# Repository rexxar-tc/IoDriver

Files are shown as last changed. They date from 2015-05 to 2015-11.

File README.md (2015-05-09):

IoDriver
========
##About the IoDriver

The IoDriver is a custom, open-source RGBW LED driver for model lightsabers. Here you'll find source code, schematics, PCB files, firmware, binaries, documentation, and various other text files.

###Full Feature List

If you've come here from Tindie, you've seen a short list of what we thought were the most important features. Here's everything:

- Cross-platform software
- Up to 5 completely customizable profiles
- Up to 4 hours of runtime
- Full-spectrum RGBW color selection
- Integrated USB charging
- Expansion modules including bluetooth, sound, and accelerometer
- Choice of red, black, or silver buttons
- Easy installation-- no soldering necessary
- All profile data is stored on the driver

###Installation

It's fairly easy to install the IoDriver. First, you need to pull out any existing electronics in your saber. The easiest way I've found is to cut off the battery holder, then pry out the button and cut that out as well. The LED housing should just unscrew, allowing you to remove the existing LED.

Everything on the IoDriver has a connector, so you just need to fit the LED then the button, and plug it into the board. Easy. You may have to get a bit creative to fit all the wires into the LED housing, but it should work. It will take some force to put the new switch in, but with some gentle persuasion, it should go smoothly.

###What's All This Profile Jazz?

You get to define up to five profiles, with 20 color steps, and settable transition times between each. You can chose transistion effects as well. Currently there is the default gradient, solid colors, and a strobe effect. You can name each profile; you get 31 characters. All profile data, including names, are stored on board, so they will appear exactly as you set them no matter where you load up the software. You can also store as many profiles as you like locally on your computer.

When your profile is selected on your saber, it starts with the first color, then runs through a gradient to the next color. How fast this happens is based on the delay time you set. When it reaches the last color, you can choose to have it either cycle backwards through the profile, or just start over at the beginning.

###Why RGB_W_ LEDs?

RGB covers most of the color spectrum, but it's hard to get very light colors, and it's impossible to get true white. The separate red green and blue LEDs don't blend that well, so 'white' comes out as three colored spots or streaks. Having a white LED lets you get a true white, or pastel colors, if that suits you.

###Buttons

The switches specified in the BOM (and that are provided on Tindie) are meant to be pressed into sabers with a 7/16” opening. They're a shielded switch with red, black, or silver buttons. 7/16” seems to be a common size, so that's what I've selected these switches for. If your saber has a different size opening, you'll need to find your own switch. You need a momentary, normally-open (or normally-off) type.

###Software

The PC-side software is written in Perl, which works naively on Linux, and ports easily to Windows. It *should* be Mac compatible, though that's not been tested yet.

The software is fairly simple: You pick a profile number, 1-5, name it, pick your first color, transistion time and effect, then you pick a second color, and a third, etc. There is a preview button so you can see what your selected color looks like on your saber. You can also re-number your profiles, which changes the order in which they cycle through.

###Expansion Modules

Currently planned are a bluetooth module, accelerometer, and a sound expansion. None are available right now, but will be released in that order. Modules plug into the port on the top of the board, then stack on top of each other. The modules are screwed into mounting posts to keep them from coming loose.

Other modules are possible; feature requests can be posted on our GitHub [issue page] (https://github.com/rexxar-tc/IoDriver/issues).

###Other Details

The IoDriver comes with a 2400mAh lithium ion cell. There's circuitry on the board that will detect most chargers, and will charge at up to 2A, given a powerful enough charger. Most smartphone chargers are capable of supplying 1A or more. At a charge rate of 2A, the battery will charge from completely dead in just over an hour, and you get over 4 hours of use.

##That's It

That's about all you need to know about the IoDriver. If you're interested in building your own, or just want the nitty-gritty details, there's more documentation in the DOC folder. There's also schematics and Gerber files for getting your own PCBs made up.

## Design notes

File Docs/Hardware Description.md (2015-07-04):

##Overview

At the base level, the IoDriver is nothing more than a PWM LED driver with some fancy software. The hardware is relatively simple and straightforward. There are three major ICs on the board; the main ATmega328(p) microcontroller, a CYC7C65213 USB to serial converter, and a TI BQ24257 lithium-ion battery charger. In addition there is a Micrel MIC2876 5v boost converter, and a CAT25160 16kB EEPROM. The relatively high current to the LEDs is switched with FDN327N N-channel MOSFETs.

##General operation description

The LEDs are pulse width modulated to change their intensities and create different colors. The profiles store RGBW values, and we use a custom algorithm to generate the gradient sequence between each RGBW color (See color.cpp and component.cpp). The button is tied to an interrupt that increments the profile, as well as shut down and wake up the processor. Profiles are stored in EEPROM, and have a fairly simple structure.

####Charging

The Cypress USB to serial converter has the capability to detect when the device is plugged into a high-current USB port. When the IoDriver is plugged in, the TI charge controller starts up in standalone mode, with a charge current of 100mA, to prevent damaging an unknown charger. The TI device has an active-low power\_good output, which the main program checks at the start of each loop. When the power_good signal is detected, the IoDriver goes into charge mode. Within 100mS, the Cypress device will have determined the charger type (how much current it can supply) and toggles the states of two of its GPIO pins. The processor waits 200mS then reads the status of these GPIO lines, decides what the charge current should be, and sends that value to the TI device over the I2C bus. The TI charge controller is internally limited to 2A, which allows a charge from completely dead in just over an hour.

While the IoDriver is in charge mode, it polls the charge controller for the charge status (either done, charging, or error), then sets the LED to a low-intensity color to reflect that. Amber for charging, green for done, and blue or putple for error. A request or incoming data from USB will interrupt this loop to send or receive profile information, or a color preview override.

During charging, the LED will stay lit for about 5 minutes, then shut off. Once charging is complete, it will come back on green for another five minutes. The system is still powered on, so it will still immediately respond to any communication from the PC software.

Blue and purple are used for error indication to avoid confusion with the normal amber color. A purple error should only occur if the IoDriver is plugged in without a battery attached, and a blue error indicates any general charge error.

####Battery information

The ATmega device periodically checks the supply voltage, and when it falls below the BATTERY\_MINIMUM threshold (3.2V), it will blink red for about 10 seconds, then go into shutdown mode. The device can be woken back up, but a flag is raised in memory, locking it into low power mode until a charger is connected. In the event that the battery is deeply discharged, the TI charge controller can detect this, and will go through an algorithm to attempt to recover the cell.

The processor does not check supply voltage while charging, so as to not bail into shutdown mode when it's plugged in.

Additionally, there is battery protection circuitry on a dedicated board attached to the cell which protects against over- and under-charge, as well as over-current situations.

###Other design notes

The latest revision (G) saw the switch from the ATmega32u4 to the ATmega328(p) processor, as well as replacing the expensive Maxim USB charge detector IC with a USB to serial converter that has that functionality built in. This reduced both cost and complexity, and allowed us to go from a 4 layer PCB back to a much cheaper 2 layer board. Part of the motivation for this was the unpredictable stock of the ATmega32u4; we had to resort to sourcing the chips from ebay because all of the regular distributors were sold out. In addition, the ATmega328 processors cost about half of the 32u4.

Revision G also marks a major change in overall board design. All of the large parts have been put on the top side of the board, allowing for easier machine assembly.

Older hardware versions had an issue where the switching FETs weren't fully turning on. Changing all of the digital circuitry to run on a 5V rail provided by the boost converter solved this problem. Because of the high current requirements, the LED supply is still taken straight from the battery.

Off current is 2mA. This is low enough to be acceptable for a 2000mAh battery. It might be possible to reduce this further.

####Expansion connectors

There are two connectors on the front of the IoDriver board that are intended for expansion modules. Currently planned are a bluetooth module (with accompanying iOS/Android apps), an accelerometer module, and a sound board.

The large connector is just an SPI bus, with two chip select lines. It also carries all power to the expansion modules, as well as acting as the first-time ISP programmer for the ATmega328. Power to the expansion port is swiched with a MOSFET to prevent the modules consuming power when the system is supposed to be in sleep mode. Because of the body diode in the MOSFET, it's also possible to power the board from this connector for initial programming.

The second connector carries the I2C and RS232 Rx/Tx lines.

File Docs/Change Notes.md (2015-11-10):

##11/10/15
-*Hardware version incremented to H*
-*Added hardware support for accent LEDs* (user request)
-Added connector for buttons with built-in LEDs
-Added support for kill-key hard power switch. This simply disables the SMPS, which reduces power use to negligible levels
-We've officially used all available GPIO

##07/04/15
-*Firmware version incrementerd to 0.5.2*
-*Hardware version incremented to G2*
-Connected D+/D- pins on bq24257 for possible future use--currently unused in firmware
-Fixed major firmware issue where device would not wake from sleep mode, and had to be power cycled
-Fixed condition with bq24257 where it could not recover from completely dead battery--also can now be powered by USB with no battery connected
##06/07/15
-*Firmware version incremented to 0.5.1*
-*Hardware version incremented to G1*
-swapped pins 1 and 2
-moved CYC7C65213 Vcc pins from Vcc to Vbus. There was a latchup issue if the device was plugged into USB without a battery connected (no Vcc)
-added R10 on CYC7C65213; this is a current limiting resistor to prevent latchup
-RESET net wasn't properly connected
-deprecated recovery format functionality -- pin 24 (analog 1) is now free

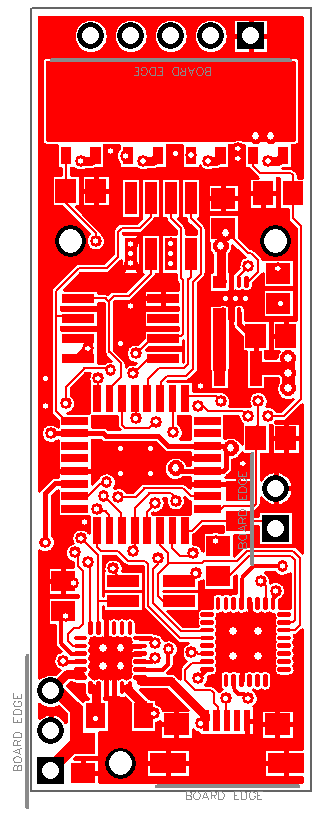
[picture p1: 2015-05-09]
Hardware/PCB-Top.bmp

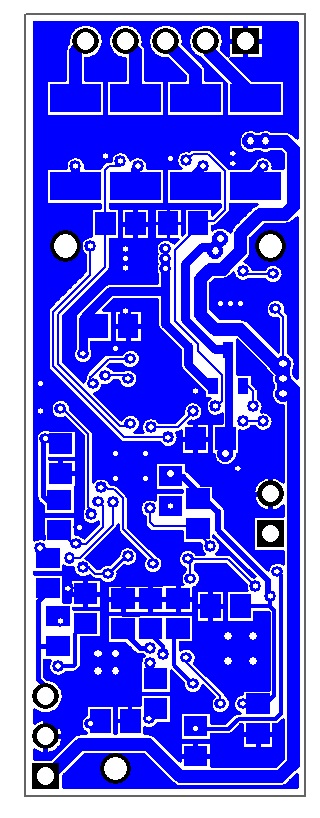
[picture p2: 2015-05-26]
Hardware/PCB-Bottom.jpg

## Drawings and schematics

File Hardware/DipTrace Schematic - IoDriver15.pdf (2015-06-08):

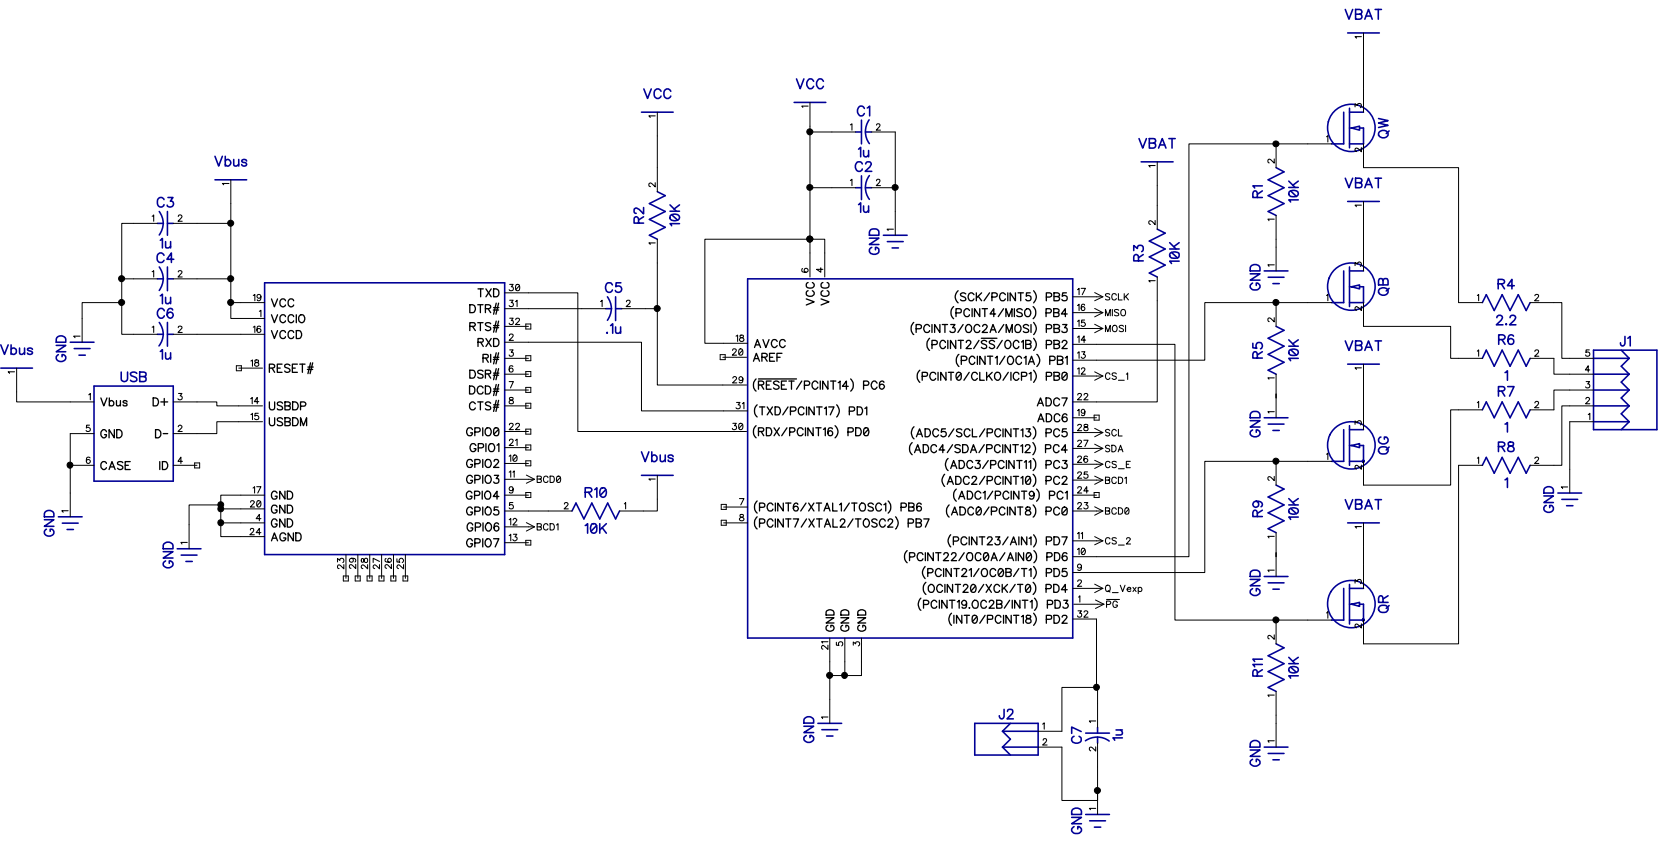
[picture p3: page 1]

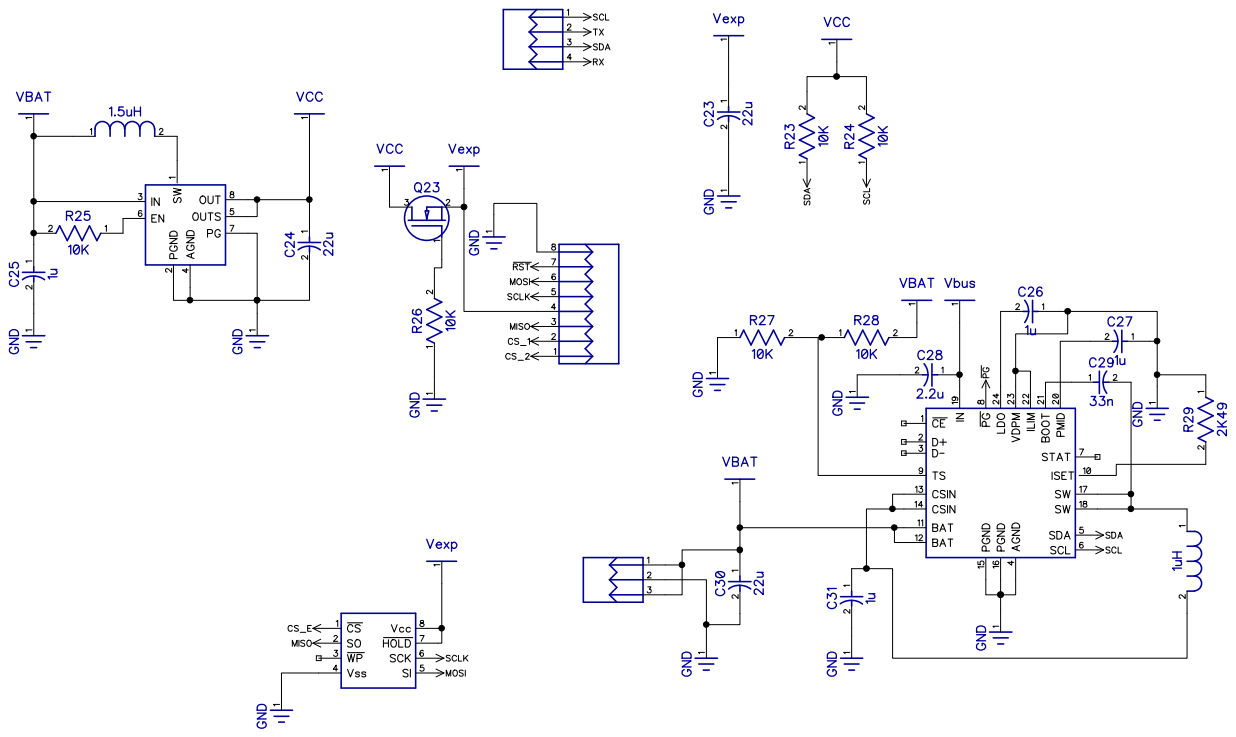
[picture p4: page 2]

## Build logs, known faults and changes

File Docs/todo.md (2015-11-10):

##ToDo
Include prebuilt firmware binaries
General code cleanup
Optimization of SPI EEPROM routines
Implement accent and button LEDs in firmware
Change pin numbers to match reassigned functions
Finish design for sound expansion
Wait for C to fix the GUI disconnect issue
Wait for C to implement accent LEDs in GUI
Wait for C to implement sound

##Bugs:
-GUI program will fail and disconnect when polling for connection status [Workaround: set polling period to 10 minutes]
-Sometimes color will freeze when plugging device in, pressing the button will switch it back to the charging color. (can't seem to reproduce?)
-Preview profile can sometimes get corrupted during transmission.
-Writing a single byte to the second EEPROM under specific conditions will fail with no warning.

##Fixed bugs:
-LED can sometimes stress SMPS to the point of overload, thermal shutdown.
Fix: changed LED supply back to battery voltage.
-Battery voltage drops due to LED current, causes premature shutdown [Workaround: battery voltage checking is disabled for now, relying on protection board]
Fix: Workaround caused Li protection circuit to isolate battery; charging circuit couldn't recover. Now averaging voltage over 10 seconds to account for voltage droop.
-Profile preview function in GUI doesn't work
Fix: program now actually checks if there's a preview profile coming in
-When resuming from sleep, it will switch to the next profile
Fix: program now checks if we're resuming from sleep; disables profile advance
-Device doesn't wake when plugged in while asleep
Fix: Moved PowerGood signal to interrupt pin
-Charge controller couldn't recover from fully discharged and isolated battery
Fix: Controller for some reason *requires* USB input to start up with no battery input: routed those connections

##Issues:
-Opening serial port causes a reset. This is by design, but GUI can't cope [Workaround: removed C4; this means firmware is not user updateable] May include manual reset button later to allow user updates.

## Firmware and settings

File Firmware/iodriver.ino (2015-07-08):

#include <cstdlib>

#include <Arduino.h>
#include <avr/sleep.h>
#include <avr/power.h>
//#include <EEPROM.h> // Don't remove this (commented) include. Needed for pre-build step parsing.
#include <Wire.h>
#include <SPI.h>
#include <SPI_io.hpp>
#include <iodriver.hpp>
#include <profile.hpp>
#include <profilehandler.hpp>
#include <EEPROMHandler.hpp>
#include <I2C.hpp>

bool plugged = false;
bool check_button = false;
bool bat_low = false;
unsigned long button_time = 0;
unsigned long average_time = 0;
int average_array[10] = {700,700,700,700,700,700,700,700,700,700};
int average_count = 0;
bool chg_preview = false;
bool sleep_tst = false;
bool is_asleep = false;

IoDriver::ProfileHandler ph;

int freeRam () {
  extern int __heap_start, *__brkval;
  int v;
  return (int) &v - (__brkval == 0 ? (int) &__heap_start : (int) __brkval);
}

void updateLED() {

    IoDriver::rgbw color;
    IoDriver::Profile* ap = ph.active();
    if ( ap ) {
        color = ap->get_color_value();
    } else {
        color = IoDriver::rgbw( 0, 0, 0, 0 );
    }
    analogWrite( PIN_LED_R, color.r );
    analogWrite( PIN_LED_G, color.g );
    analogWrite( PIN_LED_B, color.b );
    analogWrite( PIN_LED_W, color.w );
}

void setup() {
    //Serial.begin( 4800 ); //enable here for debug, otherwise when plugged in

    set_sleep_mode( SLEEP_MODE_PWR_DOWN );

    // Find all profiles' start addresses and store them,
    // then activate the first profile.
    (void)ph.enum_profiles();
    (void)ph.first_profile();

    //set pin modes
    pinMode( A1, INPUT );
    pinMode( PIN_BUTTON, INPUT_PULLUP );
    pinMode( PIN_POWERGOOD, INPUT_PULLUP );
    pinMode( PIN_BCD0, INPUT_PULLUP );
    pinMode( PIN_BCD1, INPUT_PULLUP );
    pinMode( PIN_LED_R, OUTPUT );
    pinMode( PIN_LED_G, OUTPUT );
    pinMode( PIN_LED_B, OUTPUT );
    pinMode( PIN_LED_W, OUTPUT );
    pinMode( PIN_CS_E, OUTPUT );
    pinMode( PIN_Vexp, OUTPUT );

    digitalWrite( PIN_Vexp, HIGH );     //turn on power to expansion bus

    attachInterrupt( 0, buttonPressed, FALLING );   //go to buttonPressed() when button on pin 2 goes from high to low
    attachInterrupt( 1, wakePlugged, FALLING );     //gp to wakePlugged() when device plugged into usb

    Wire.begin();
    SPI.begin();
}

void loop()
{
    checkPG();
    if ( !plugged )
    {
        //check battery voltage
        if (checkVoltage() < BATTERY_MINIMUM || bat_low == true )
        {
            bat_low = true;
            for( int b = 0; b < 5; ++b)
                blinkRed();

            disableCharge();
            digitalWrite( PIN_Vexp, LOW );   //turn off power to expansion bus
            sleep_enable();
            sleep_mode();
            digitalWrite( PIN_Vexp, HIGH );  //turn on power to expansion bus
        }

        else
        {
            if ( check_button ) {
                // If button is up, stop checking, increment profile, and re-enable button interrupts
                if ( digitalRead( PIN_BUTTON ) != 0 ) {
                    check_button = false;
                    ph.next_profile();

                // If button is still down, check whether it has
                // been down for 2 seconds
                } else {
                    unsigned long time_now = millis();
                    if ( time_now - button_time >= TIME_TO_SLEEP ) {
                        // Turn off the LEDs
                        digitalWrite( PIN_LED_R, LOW );
                        digitalWrite( PIN_LED_G, LOW );
                        digitalWrite( PIN_LED_B, LOW );
                        digitalWrite( PIN_LED_W, LOW );
                        check_button = false;
                        is_asleep = true;
                        digitalWrite( PIN_Vexp, LOW );      //turn off power to expansion bus
                        PRR |= 0b10000111;                  //turn off ADC, I2C, and UART
                        sleep_enable();
                        sleep_mode();
                        PRR &= 0b01111000;                  //turn on ADC, I2C, and UART
                        digitalWrite( PIN_Vexp, HIGH );     //turn on power to expansion bus
                    }
                }
            }
        updateLED();
        }
    }
    else if ( plugged && !chg_preview )
    {
        checkSerial();
        chargeState();
    }
    else if ( plugged && chg_preview == true )
    {
        checkSerial();
        updateLED();
    }
}

void buttonPressed()
{
    sleep_disable();
    //if we've just resumed from sleep, set check_button false so we don't change profile
    if ( is_asleep )
    {
        is_asleep = false;
        check_button = false;
        return;
    }
    if ( check_button )
        return;

    check_button = true;
    button_time  = millis();
}

void wakePlugged()
{
    sleep_disable();    //wake up system from sleep on charger connect
}

void checkPG()
{
    if ( digitalRead (PIN_POWERGOOD) == LOW && !plugged )       //if charge IC reports plugged in, and we weren't previously
    {
        plugged = true;
        Serial.begin(BAUDRATE);
        setupCharge();
        detachInterrupt(0);                                     //detach button interrupt
        attachInterrupt(0, buttonPressedCharge, FALLING );      //attach new interrupt to check battery state while charging
        bat_low = false;                                        //reset bat_low
        is_asleep = false;
    }

    else if ( digitalRead (PIN_POWERGOOD) == LOW && plugged)    //if charge IC reports plugged in, and we were previously
    {
        //do nothing
    }

    else if ( digitalRead (PIN_POWERGOOD) == HIGH && plugged)   //if charge IC reports unplugged
    {
        plugged = false;
        Serial.end();
        disableCharge();
        detachInterrupt(0);
        attachInterrupt( 0, buttonPressed, FALLING );           //and re-enable the interrupt
        chg_preview = false;                                    //cancel profile preview
        ph.first_profile();                                     //switch to first profile
    }

    else
    {
        plugged = false;        //just in case.
    }
}

void blinkRed()
{
    analogWrite(PIN_LED_R, 0);
    analogWrite(PIN_LED_G, 0);
    analogWrite(PIN_LED_B, 0);
    analogWrite(PIN_LED_W, 0);  //turn off all LEDs
    analogWrite(PIN_LED_R, 50); //turn on red LED
    delay(1000);                //wait one second
    analogWrite(PIN_LED_R, 0);  //turn it back off
    delay(2000);                //wait two seconds
    analogWrite(PIN_LED_R, 0);
    analogWrite(PIN_LED_G, 0);
    analogWrite(PIN_LED_B, 0);
    analogWrite(PIN_LED_W, 0);  //turn off all LEDs
    analogWrite(PIN_LED_R, 50); //turn on red LED
    delay(1000);                //wait one second
    analogWrite(PIN_LED_R, 0);  //turn it back off
    delay(2000);                //wait two seconds
}

int checkVoltage()
{
    long average_hold = 0;
    if( millis() - average_time >= 1000 )
    {
        average_array[average_count] = analogRead( PIN_BATTERY );
        average_time = millis();
        for( int a = 0; a < 10; ++a)
        {
            average_hold += average_array[a];
        }
        average_hold /= 10;

        if( average_count == 9 )
            average_count = 0;
        else
            average_count ++;

        return average_hold;
    }
    else
    {
        for( int a = 0; a < 10; ++a)
        {
            average_hold += average_array[a];
        }
        average_hold /= 10;
        return average_hold;
    }
}

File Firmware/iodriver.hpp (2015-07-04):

#ifndef _IODRIVER_HPP
#define _IODRIVER_HPP

#define FIRMWARE_VERSION_NUMBER	        "0.5.2"

#ifndef HARDWARE_VERSION_NUMBER
#define HARDWARE_VERSION_NUMBER         "G"
#endif

#define BAUDRATE                        57600 //serial port speed
#define SERIAL_DELAY                    1    //ms
//Pin definitions

#define PIN_BUTTON                  	2
#define PIN_POWERGOOD               	3
#define PIN_LED_W                   	6
#define PIN_LED_B                   	9
#define PIN_LED_G                   	5
#define PIN_LED_R                   	10
#define PIN_BCD0                        A0
#define PIN_BCD1                        A2
#define PIN_BATTERY                     A7

//power settings

#define TIME_TO_SLEEP                   2000 // milliseconds

                                             // ADC units
#define BATTERY_FULL                    839  // 4.1V
#define BATTERY_MINIMUM             	655  // 3.2V
#define BATTERY_CRITICAL            	614  // 3V
#define ADC_CONVERSION                  4.883  //converts ADC units to mV

#define TIME_INTERVAL_CONVERSION_FACTOR	10	// Multiply time interval by this to get milliseconds

//declarations

void buttonPressed();
void checkSerial();
void checkPG();
void setup_EE2();
void blinkRed();
int checkVoltage();
void checkVoltDebug();
void buttonPressedCharge();
void wakePlugged();

extern bool chg_preview;

/**
 * Data storage parameters
 **/
// Data formatting specs
#define CAL_OFFSET                       1025
#define BAT_LOW
#define EEPROM1_FIRST_PROFILE_OFFSET        0
#define PROFILE_INDEX_OFFSET                0
#define PROFILE_INDEX_SIZE                  1
#define PROFILE_NAME_OFFSET                 1
#define PROFILE_FIRST_DATA_OFFSET          32
#define PROFILE_COLOR_UNIT_SIZE             8
#define PROFILE_DATA_UNIT_SIZE              8
//#define PROFILE_COLOR_RGBW_OFFSET           0
//#define PROFILE_COLOR_TIME_INTERVAL_OFFSET  4
//#define PROFILE_COLOR_TIME_INTERVAL_SIZE    2
//#define PROFILE_COLOR_END_FLAG_OFFSET       6
#define PROFILE_DATA_TYPE_OFFSET            0
#define PROFILE_COLOR_RGBW_OFFSET           1
#define PROFILE_COLOR_TIME_INTERVAL_OFFSET  5
#define PROFILE_COLOR_TIME_INTERVAL_SIZE    2
#define PROFILE_COLOR_EFFECT_FLAGS_OFFSET   7
#define PROFILE_DATA_TYPE_COLOR             1
// Data limitations
#define EEPROM1_MAX_PROFILES                5
#define PROFILE_MAX_SIZE                    200
#define PROFILE_NAME_MAX_CHARS              31
#define PROFILE_MAX_DATACOUNT               21
// Specifications
#define EEPROM1_SIZE                        1024 // Used in EEPROMHandler
#define EEPROM2_SIZE                        16384
#define EEPROM_TOTAL                        EEPROM1_SIZE + EEPROM2_SIZE

#define EEPROM_H_VIRTUAL_SIZE               PROFILE_MAX_SIZE // Used in EEPROMHandler
#define HAS_SECONDARY_EEPROM

#endif // _IODRIVER_HPP

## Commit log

2014-04-20 Added schematic and PCB files
    Both in DipTrace format.
2014-05-23 Introduced Rev D changes
    [IoDriverRevC.gbl, IoDriverRevC.gbo, IoDriverRevC.gbs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]
2014-07-29 Vast and sweeping changes
    Decided to not use GitHub for a few months, then changed our mind, oops.
    [IoDriverRevC.gbl, IoDriverRevC.gbo, IoDriverRevC.gbs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]
2015-01-08 Rev G overhaul
    Completely redesigned hardware. Check HardwareDescription.md/design
    notes
    [IoDriver15.gbl, IoDriver15.gbo, IoDriver15.gbs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]
2015-01-08 Cleanup
    Accidentally left some Rev F files in place-- deleted those
    [IoDriverRevF.gbl, IoDriverRevF.gbo, IoDriverRevF.gbs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]
2015-04-15 Added SMPS to driver board
    Greatly increases brightness! Various improvements to software, remove
    shift register from board, added connector for bluetooth module.
    [IoDriver15.gbl, IoDriver15.gbo, IoDriver15.gbs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]
2015-04-22 Include USB Driver installer
2015-05-09 Added PDF schematic
2015-05-09 Fixed power supply issue
    Connected LED to battery rather than SMPS, this is more efficient.
2015-05-26 Update Schematic and PCB. NEW: Sound Module!
2015-06-08 New FW version 0.5.1
    Includes many bug fixes and minor hardware changes (now rev. G1)
    [I2C.cpp, SPI_io.cpp, SPI_io.hpp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]
2015-07-04 Minor board tweak
2015-07-08 Added power saving code, cleaned up a few things
2015-11-10 Added provision for accent LEDs, hard power switch
    Also added connector for switches with built-in LEDs.
    See Docs\Change Notes
